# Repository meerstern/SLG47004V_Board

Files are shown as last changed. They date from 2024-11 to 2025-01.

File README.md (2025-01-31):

# SLG47004V変換基板　SLG47004V Board

## 概要 
  * GreenPAK [SLG47004V][1]を搭載した変換基板です 
  * オペアンプ、デジタルレオスタット、EEPROM、アナログおよびデジタルマクロセルを備えています    
  * I2Cを介して機能を何度も書き換えることが可能です(最大1000回程度)    
  * SLG47004Vの全てのIOにアクセスすることが可能です  
  * I2CはGrove互換コネクタを搭載しています
  * LED点滅のサンプルプロジェクト及びバイナリを用意しています(市販LEDをIO2に接続)
  * 同じ書き換え可能なタイプのSLG46826に比べてSLG47004Vはアナログ系が強化されています  

## 仕様  
  * 開発は無料のソフトウェア[Go Configure Software Hub][2]を使用してください  
  * 書き込みは[純正プログラマ][3]、[Arduino][4]もしくは[USBシリアルI2C変換基板とWebツール][5]を使用してください  
  * デジタル電源とアナログ電源は内部のFBで接続されています
  * 電源電圧DC2.5V-5.0V(絶対定格2.4V-5.5V)
  * サイズ30mm x13mm (突起部、コネクタ除く)

## 外観
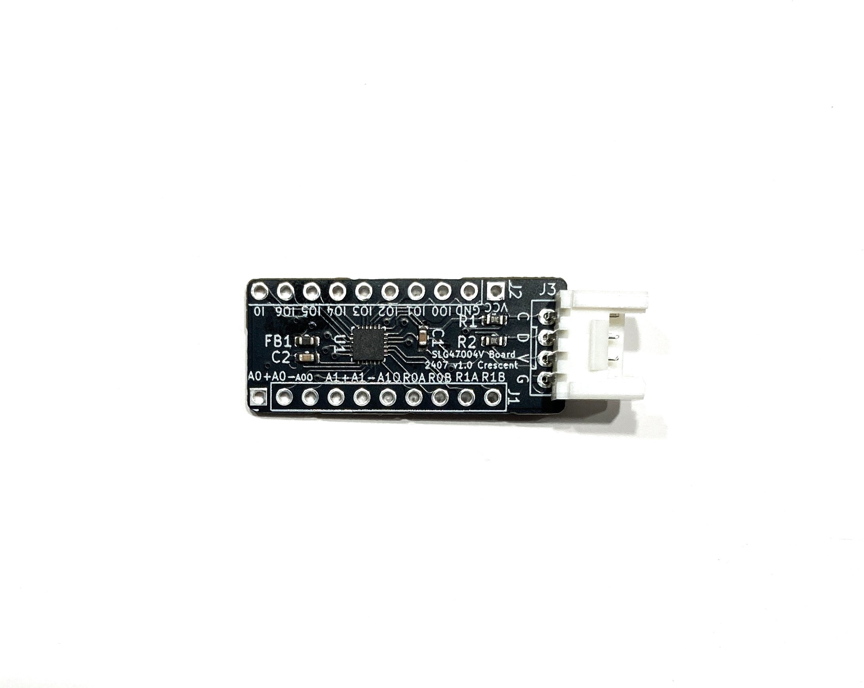
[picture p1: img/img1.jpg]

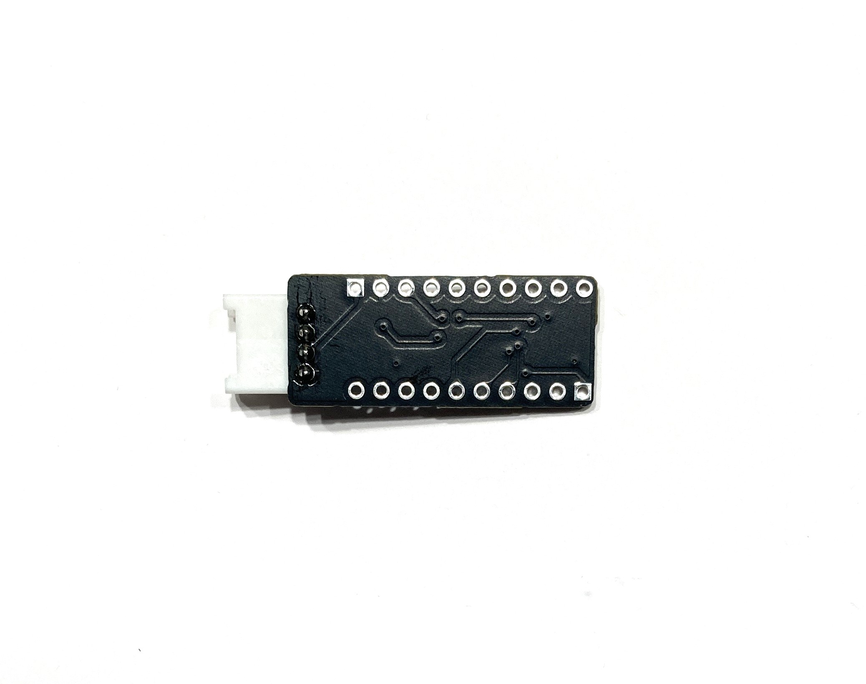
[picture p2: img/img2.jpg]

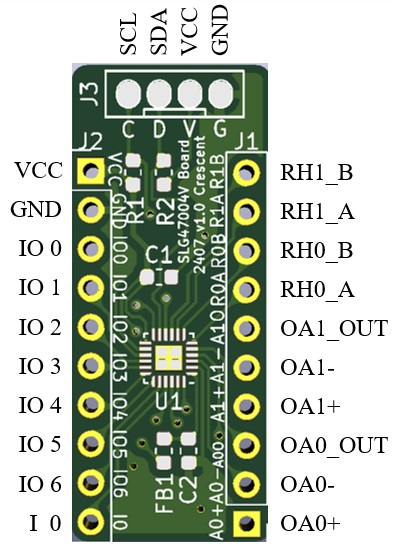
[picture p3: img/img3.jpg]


[1]: https://www.renesas.com/ja/products/programmable-mixed-signal-asic-ip-products/greenpak-programmable-mixed-signal-products/analogpak/slg47004-programmable-mixed-sign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
[2]: https://www.renesas.com/ja/software-tool/go-configure-software-hub
[3]: https://www.renesas.com/ja/products/programmable-mixed-signal-asic-ip-products/greenpak-programmable-mixed-signal-products/slg4dvkgsd-greenpak-serial-debugger-board-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
[4]: https://www.renesas.com/ja/document/apn/cm-255-slg468246-mtp-arduino-programming-example
[5]: https://meerstern.github.io/web_serial_greenpak_writer.html

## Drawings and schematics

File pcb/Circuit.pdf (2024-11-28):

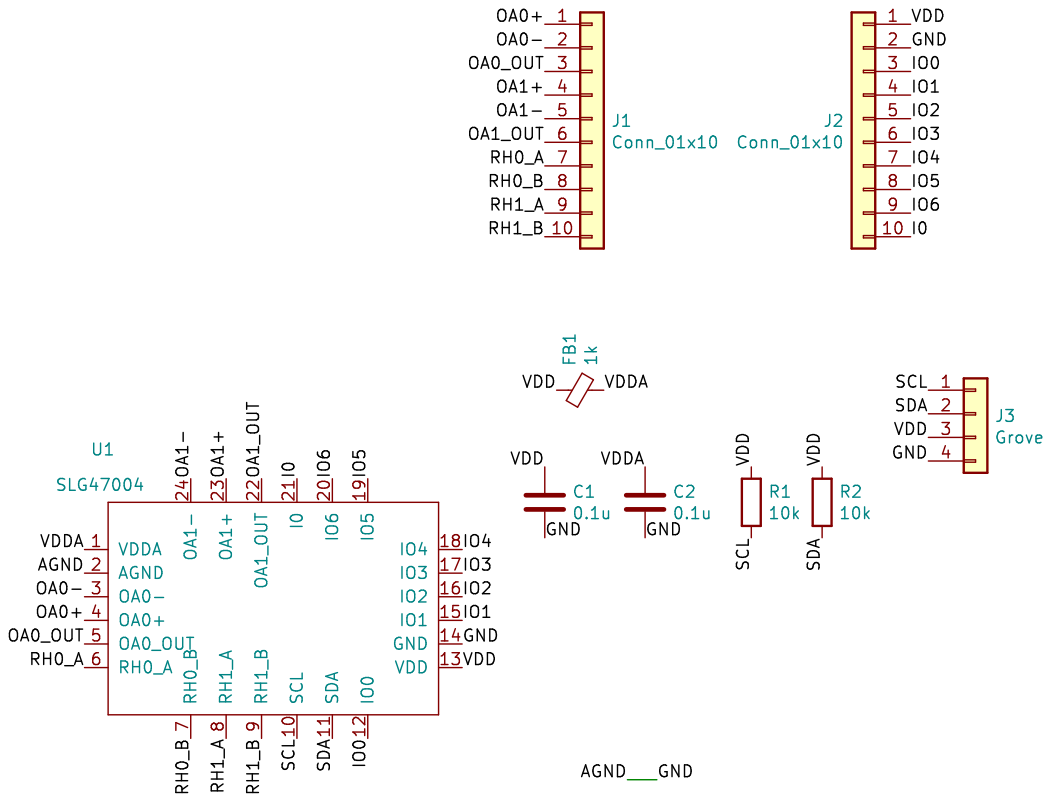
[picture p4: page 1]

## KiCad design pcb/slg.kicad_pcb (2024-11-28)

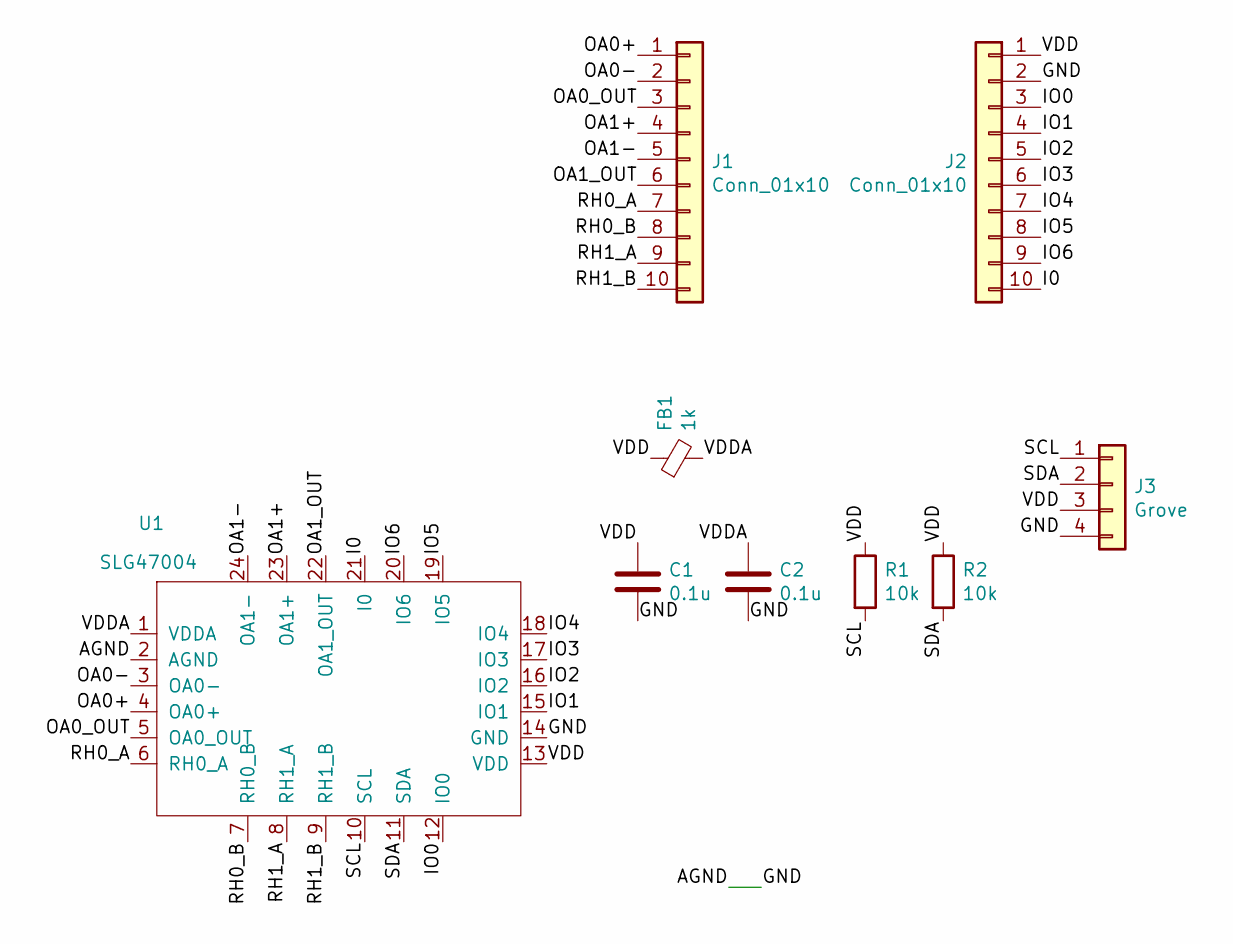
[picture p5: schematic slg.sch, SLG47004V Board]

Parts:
C1, C2: 0.1u; C_0603_1608Metric
FB1: 1k; L_0603_1608Metric
J1, J2: Conn_01x10; PinHeader_1x10_P2.54mm_Vertical
J3: Grove; GROVE
R1, R2: 10k; R_0603_1608Metric
U1: SLG47004; QFN-24-1EP_3x3mm_P0.4mm_EP1.75x1.6mm

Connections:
/AGND: C1.2, C2.2, J2.2, J3.4, U1.2 (AGND), U1.14 (GND)
/I0: J2.10, U1.21 (I0)
/IO0: J2.3, U1.12 (IO0)
/IO1: J2.4, U1.15 (IO1)
/IO2: J2.5, U1.16 (IO2)
/IO3: J2.6, U1.17 (IO3)
/IO4: J2.7, U1.18 (IO4)
/IO5: J2.8, U1.19 (IO5)
/IO6: J2.9, U1.20 (IO6)
/OA0+: J1.1, U1.4 (OA0+)
/OA0-: J1.2, U1.3 (OA0-)
/OA0_OUT: J1.3, U1.5 (OA0_OUT)
/OA1+: J1.4, U1.23 (OA1+)
/OA1-: J1.5, U1.24 (OA1-)
/OA1_OUT: J1.6, U1.22 (OA1_OUT)
/RH0_A: J1.7, U1.6 (RH0_A)
/RH0_B: J1.8, U1.7 (RH0_B)
/RH1_A: J1.9, U1.8 (RH1_A)
/RH1_B: J1.10, U1.9 (RH1_B)
/SCL: J3.1, R1.2, U1.10 (SCL)
/SDA: J3.2, R2.2, U1.11 (SDA)
/VDD: C1.1, FB1.1, J2.1, J3.3, R1.1, R2.1, U1.13 (VDD)
/VDDA: C2.1, FB1.2, U1.1 (VDDA)

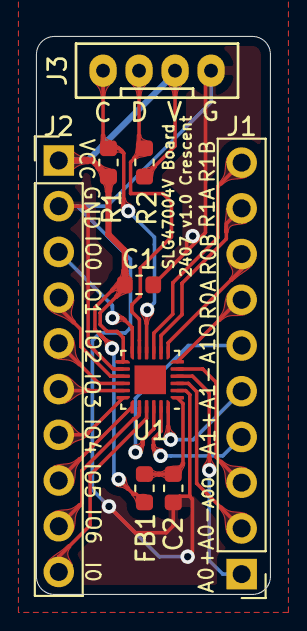
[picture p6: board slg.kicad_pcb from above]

Board: 2 copper layers, 13.0 x 31.0 mm, 9 parts (0 on the bottom side), 23 nets.
